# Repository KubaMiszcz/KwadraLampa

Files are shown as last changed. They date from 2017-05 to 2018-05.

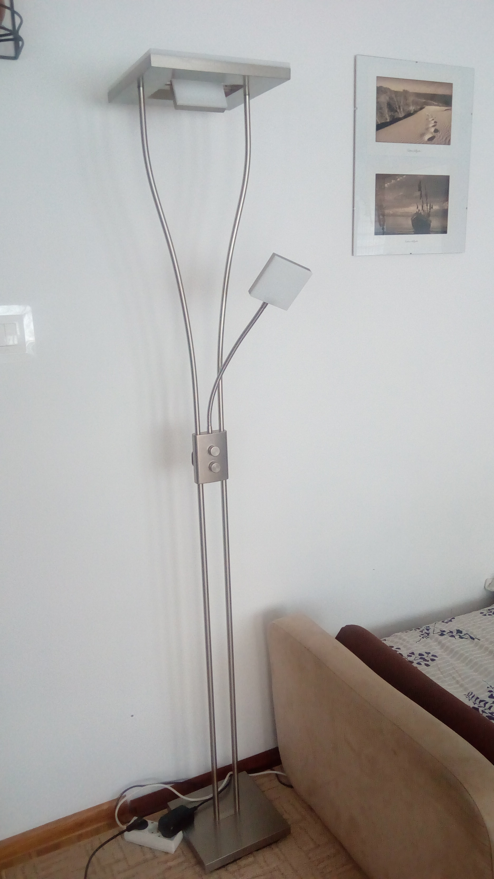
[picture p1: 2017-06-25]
foto/2017-06-14 105750.jpg

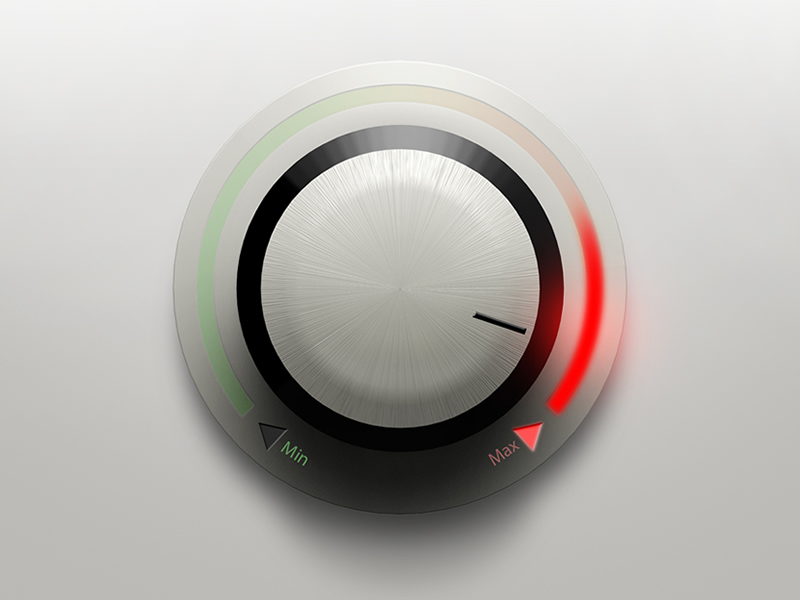
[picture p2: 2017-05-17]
grafiki/rotary knob/ui-button-smooth-red-800x600.jpg

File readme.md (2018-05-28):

# KwadraLampa
## TODO:
* rewrite to STM32F103
* communication through wifi - mosquitto and openhab
* redesign PCB for it

## Android App
* ikonka help i about
* ikonka powrot do glownego
* pamietanie ostatniego nadajnika i laczenie automatyczne
* krotkie nazwy nadajnikow
* usun dzwieki na razie bo cos sie krzwayc i za dlugo trwaja nawt po wylaczneiu

## PC Client
* todo

## Arduino firmware
sprawdz czy arduino wysyla co 100ms 10ms przy 9600, jak tak to kombinu z xamarinem:]
ustwiaenia BT i inne do ekranu ustwaienia
komunikacja w obie strony

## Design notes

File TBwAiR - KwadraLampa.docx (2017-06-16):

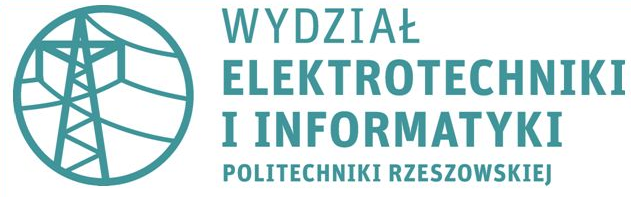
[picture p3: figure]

Dokumentacja do projektu z przedmiotu:

Technologie Bezprzewodowe w Automatyce i Robotyce

Sterownik BlueTooth

do Lampy LED

KwadraLampa

LP1 C1, EADI-3

Bełch Jakub

Rzeszów, IV 2017

1. Cel i zakres projektu

Projekt miał na celu wykonanie sterownika do pokojowej stojącej Lampy LED, można go również użyc do innych zastosowań. Zakres obejmował wykonanie firmwaru do mikrokontorolera oraz klienta na Android i PC. Z braku czasu na tę chwilę zrezygnowałem z wykonania klienta na PC.

Podstawowe założenia:

- właczanie/wyłaczanie lamp
- regulacja jasności
- właczanie/wylaczanie po zadanym czasie – TIMER
- właczanie/wyłaczanie o zadanej godzinie – CLOCK

Dodatkowo w trybach CLOCK i TIMER mozna ustawic opcje ze zamiast naglego wylaczenia po zadanym czasie lampa sciemnia/rozjasnia sie stopniowo do 0/255 w ciagu tego czasu.

Na razie w trybach timer i clock działa tylko wyłączanie, muszę pomyśleć jak zrealizować to rozróżnienie

Komunikacja bezprzewodowa realizowana jest przez dowolny modul BT w trybie SPP

2. Ogólny opis rozwiązania

Zadanie było w miarę proste jednak wymagało troche czasu zeby wszystko dzialalo wygodnie. sterowanie realizowane jest w dwoch trybach MANUAL i BLUTUTU. Obsluga obu lamp jest identyczna.

tryb Manual:

Wykorzystalem dostepny fizyczny interfejs tzn dwie galki, z braku potencjometrow z wylacznikiem, wylaczanie polega na skreceniu potencjometrow na 0, regulacja polega na kreceniu galkami. Lampa ma byc prosta intuicyjna w oblsudze i wygodna dla postronnych osob dlatego nie mnozylem dalszych kontrolek

tryb Blututu:

Realizowany jest na zasadzie przesylanie kilkunastu komunikatow sterujacych plytka. Dostepne opcje:

- gaszenie/zapalanie przyciskiem
- regulacja jasnosci
- właczanie/wylaczanie po zadanym czasie – timer
- właczanie/wyłaczanie o zadanej godzinie – clock

Dodatkowo w trybach clock i timer mozna ustawic opcje ze zamiast naglego wylaczenia po zadanym czasie lampa sciemnia sie stopniowo do 0 w ciagu tego czasu (nieliniowo poniewaz jasnosc diody nie maleje liniowo wraz z pradem).

Przed podlaczeniem konieczne jest sparowanie urzadzenia z telefonem

Aaby moc korzystac z trybu clock konieczna jest znajomosc rzeczywistego czasu, poniewaz nie jest to jakos szczegolnie wazne zrezygnowalem z jakiegos modulu podtrzymywania/pobierania go, a rozwiazalem to w ten sposob ze po polaczeniz Klientem na ktorym mamy aktualny czas jest on przesylany i uaktualniany w sterowniku,

Czas w sterowniku przekreca sie co ok 40 dni, i kasuje po zaniku zasilana, jednak przy sterowaniu recznym i tak jest zbedny a po polaczeniu z BT jest ustawiany wiec ten problem uznalem za rozwiazany

Komunikaty sterujace:

3. Komunikaty do sterownika

Długosc komunikatu 11znakow (wazne! aczkolwiek firmware dopelnia sam do 11 znakow jesli dostał krotszy komunikat, jesli dostal dluzszy, sprawdza ostatnie 11znakow)

Liczby lepiej byłoby przesylac jako bajty (krocej) ale potem trza by konwertowac na stringi, na etapie prototypowania prosciej wysylac jako stringi/char.

Tak samo tryby i w ogole komunikaty, docelowo lepiej przerobic na typ ENUM i wtedy wysylamy jako jeden bajt caly string – ale trzeba by wtedy pamietac w terminalu te "kody" trybow

Spis komunikatów:

Zapytania do sterownika:
::HM:? | Przeslanie aktualnego czasu ze sterownika do klienta
::L1:? | Odsyla stan lampy do klienta
::L1:DIM? | Odsyla stan opcji sciemniania do klienta
::L1:BRGHT? | Odsyla aktualna jasnosc lampy

Ustawienia sterownika:
::HM:hhmm | Przeslanie aktualnego czasu do sterownika
::L1:on ::L1:off | Wyl/zal lampy 1
::L1:PWM5 ::L1:PWM55 ::L1:PWM255 | Przeslanie zadanej jasnosci
::L1:DIMon ::L1:DIMoff | Wyl/zal sciemnianie opcji sciemniania dla trybu timer i clock
::L1:CLhhmm ::L1:CLhhmm | Wyl/zal lampy o zadanej godzinie
::L1:TIM5 ::L1:TIM55 ::L1:TIM255 | Wyl/zal lampy po zadanym czasie
::L1:TIcncl | Anulowanie timera
::L1:CLcncl | Anulowanie clock
::L1:TGLon | Po zadanym czasie/godzine lampa sie wlacza
::L1:TGLoff | Po zadanym czasie/godzine lampa sie wylacza

Analogicznie dla lampy L2 ,Szczegolowy opis firmware – dalej

4. Sprzęt

Lampa

Lampa sklada sie z dwoch modułów LED 20W + 4W, sterowanie kazda lampa osobno, wylaczenie lampy realizowane jest przez skrecenie jasnosci do 0, lub ustawienie jej programowo na 0 (zatkanie tranzystora MOSFET)

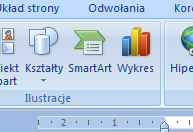
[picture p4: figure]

ZDJECIE

Płytka PCB

W zwiazku z zasilaniem 20V i maksymalnym prądem ok 1A konieczne bylo zastosowanie tranzystora sterowanego PWM (0-255 ok. 1kHz) jako regulatora, wybor padl na MOSFET IRFZ44N gdyz jest w miare uniwerslany, miałem go pod ręka, dla takich parametrów prawie sie nie grzeje (nie trzeba radiatora), i pobiera duzo mniej mocy niz analogiczny bipolarny.

Logikę zrealizowałem za pomocą mikrokontrolera Atmega8A z bootloaderem Arduino

zdjecie i schemat

Klienty

- Android – telefon z androidem, apka w AppInventor
- PC – dowolny terminal RS, lub program np w C# + kontrolka SerialPort

Firmware

Platforma Arduino, C++, programowanie obiektowe

5. Opis firmware

wiekszosc jest wyjasniona w komentarzach w kodzie

Ogolnie firmware posiada klase Lampa, i dwa obiekty tej klasy, zestaw metod do nich, plus pomocnicze statyczne metody w SharedObjectsClass, enumerator trybow, operacje na czasie itp.

podczas dzialania sprawdza stan na pinach. po wykryciu prawidlowego komunikatu przechodzi w tryb BT, nie obowiazuja wtedy ustawienia galek, po wykryciu zmiany na galkach przestaja obowiazywac ustawienia BT (zerowane sa timery)

oblsuga trybu CLOCK jest zrealizowana za pomoca trybu timer – jest wyliczany czas miedzy zadana godizna i aktualna i wykonywana metoda dla TIMER

6. Podsumowanie i Wnioski

brak pamieci

stm32

app inventor

7. Planowane Upgrady

Klient Android

- dzwieki on/off
- krotkei nazwy nadajnikow na liscie
- domsylny nadajnik zapisz , zapis aktulany jako odmyslny
- lacz przy starcie z domyslny,
8. do zrobienia
9. ogolnie
- wylaczanie o zadanej godzinie
- rozjasnianie
10. ==========APKA ANDROID
- ikonka help i about
- ikonka powrot do glownego
- pamietanie ostatniego nadajnika i laczenie automatyczne
- krotkie nazwy nadajnikow
- usun dzwieki na razie bo cos sie krzwayc i za dlugo trwaja nawt po wylaczneiu
11. ==========PROGRAM PC
12. ==========FIRMWARE ARDUINO
13. ==========inne
- zaloz konto GOOGLE PLAY
- jak przyspieszyc ten BT
- sprawdz czy arduino wysyla co 100ms 10ms przy 9600, jak tak to kombinu z xamarinem:]
- ustwiaenia BT i inne do ekranu ustwaienia
- komunikacja w obie strony
- hithub repo
15. Rozwiązania konstrukcyjne

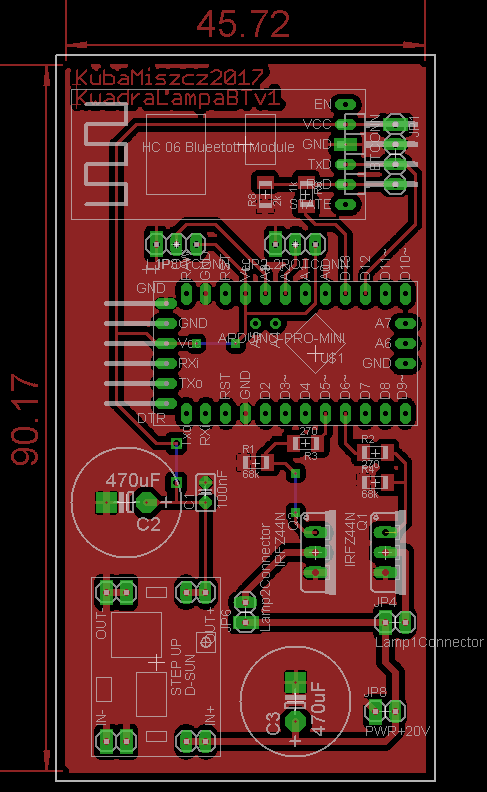
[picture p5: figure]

Konstruk).

17. Algorytm

XXXXXXX

18. Napotkane Problemy

wysylaniue co 1sek

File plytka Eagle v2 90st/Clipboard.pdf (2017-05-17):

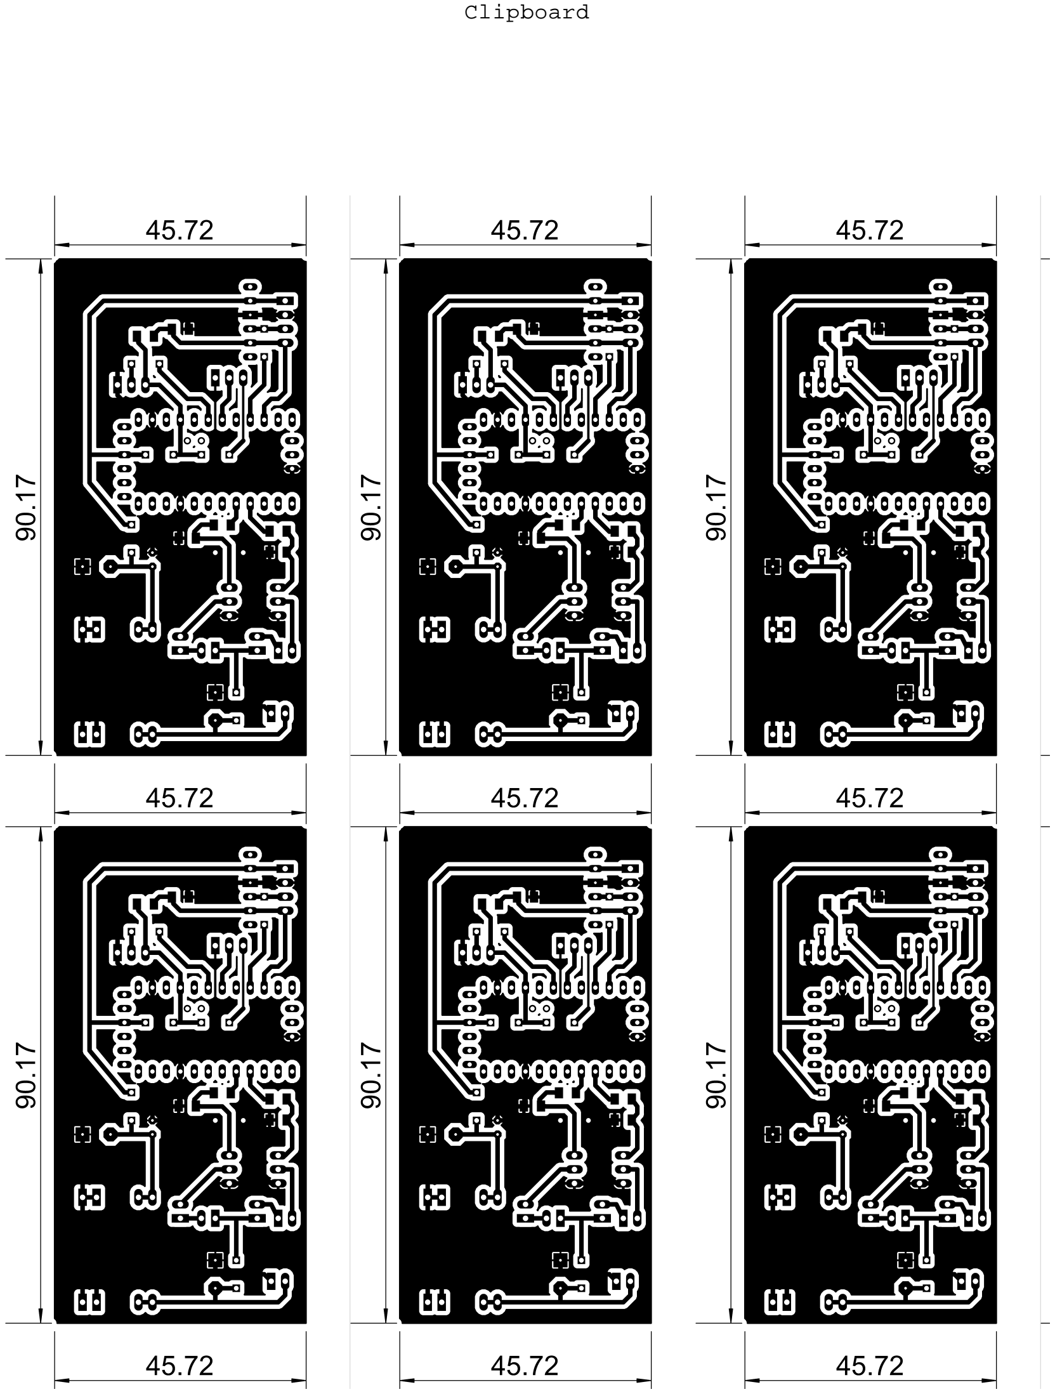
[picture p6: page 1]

Clipboard

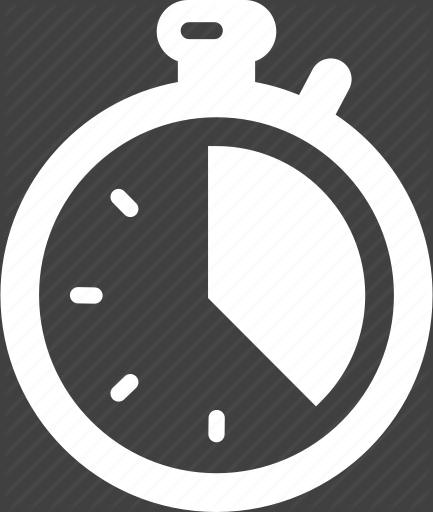
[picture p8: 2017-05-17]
grafiki/=accepted/Timer-512inv.png

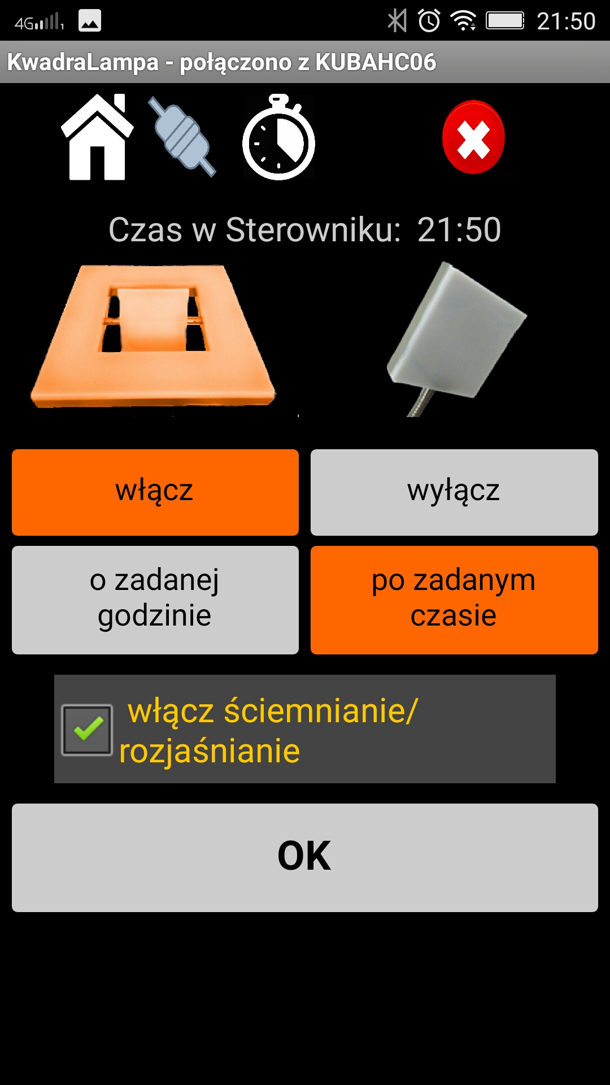
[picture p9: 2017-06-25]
foto/Screenshot_20170625-215026-410.jpg

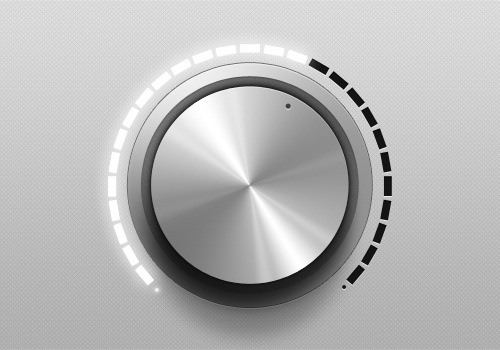
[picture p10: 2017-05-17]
grafiki/rotary knob/4-33-beautiful-volume-dials.jpg

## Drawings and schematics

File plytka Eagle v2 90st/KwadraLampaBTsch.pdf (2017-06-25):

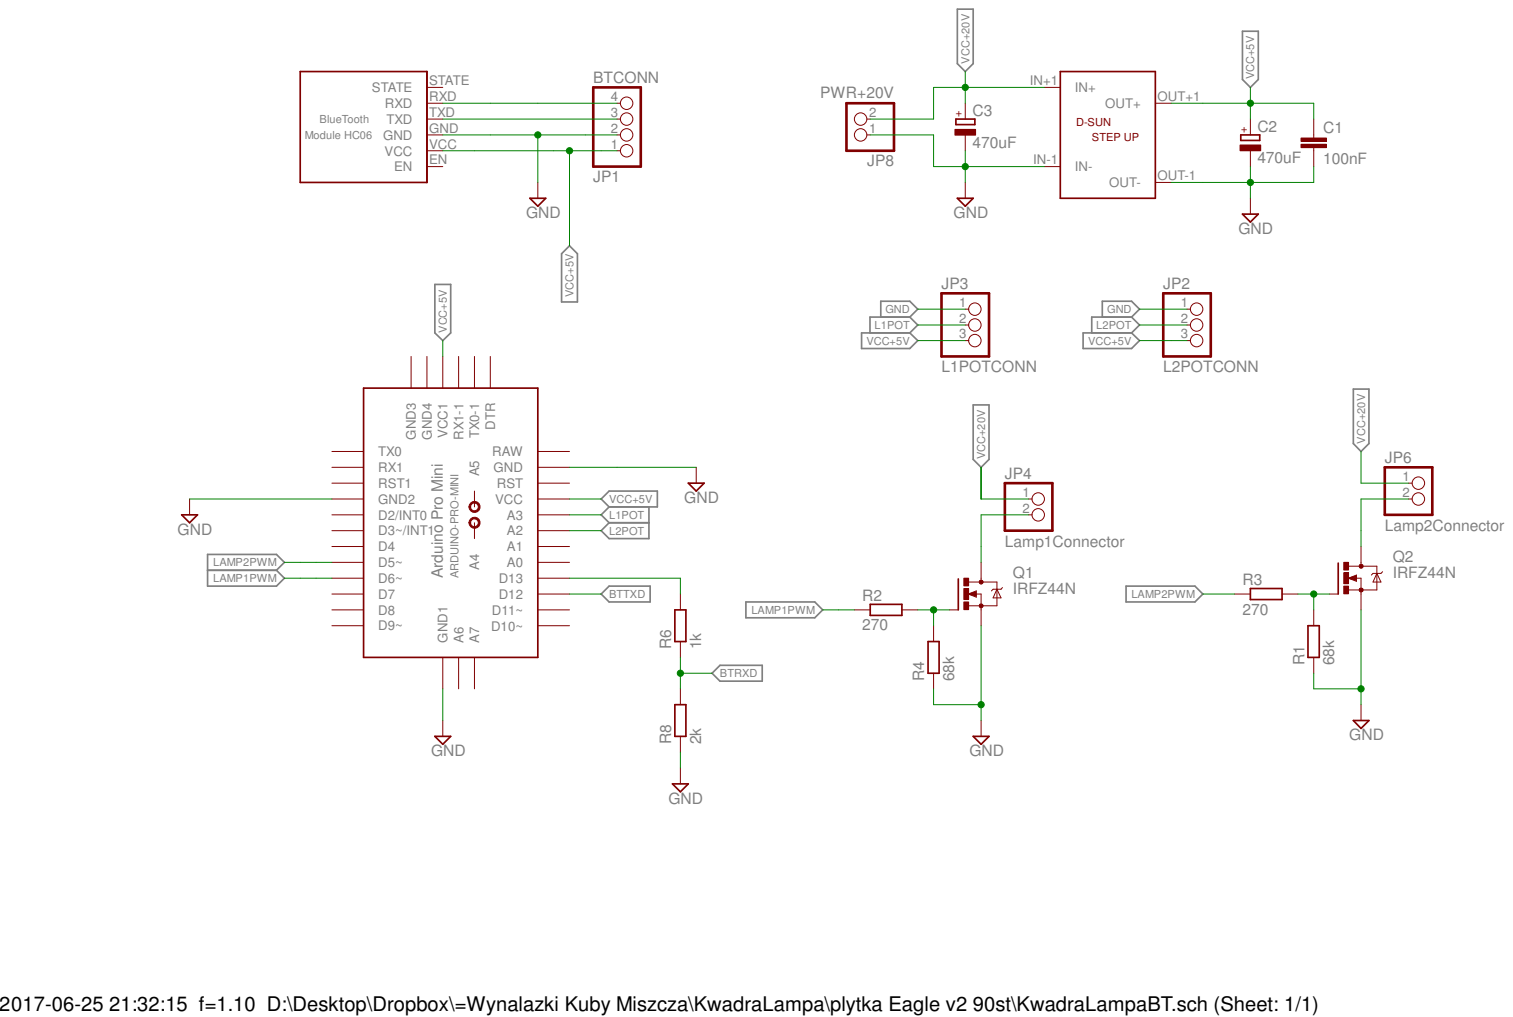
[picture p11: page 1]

ARDUINO-PRO-MINI GND

2017-06-25 21:32:15 f=1.10 D:\Desktop\Dropbox\=Wynalazki Kuby Miszcza\KwadraLampa\plytka Eagle v2 90st\KwadraLampaBT.sch (Sheet: 1/1)

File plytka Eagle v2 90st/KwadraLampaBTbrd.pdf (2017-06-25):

45.72

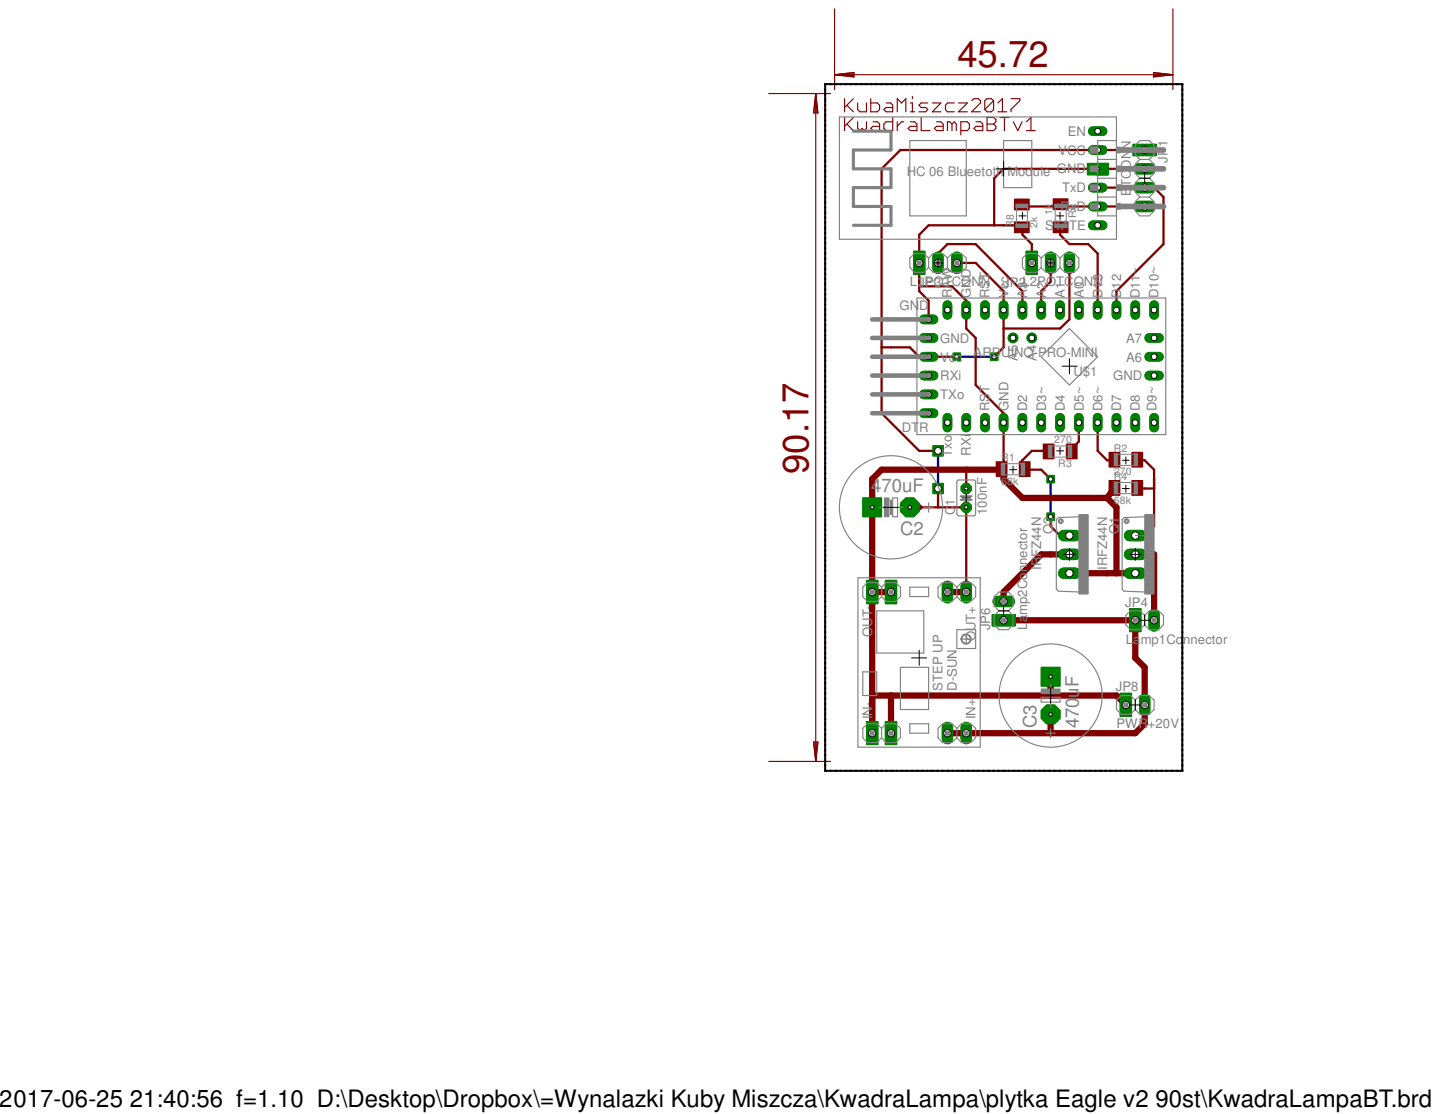
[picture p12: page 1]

L2POTCONN

TXo

2017-06-25 21:40:56 f=1.10 D:\Desktop\Dropbox\=Wynalazki Kuby Miszcza\KwadraLampa\plytka Eagle v2 90st\KwadraLampaBT.brd

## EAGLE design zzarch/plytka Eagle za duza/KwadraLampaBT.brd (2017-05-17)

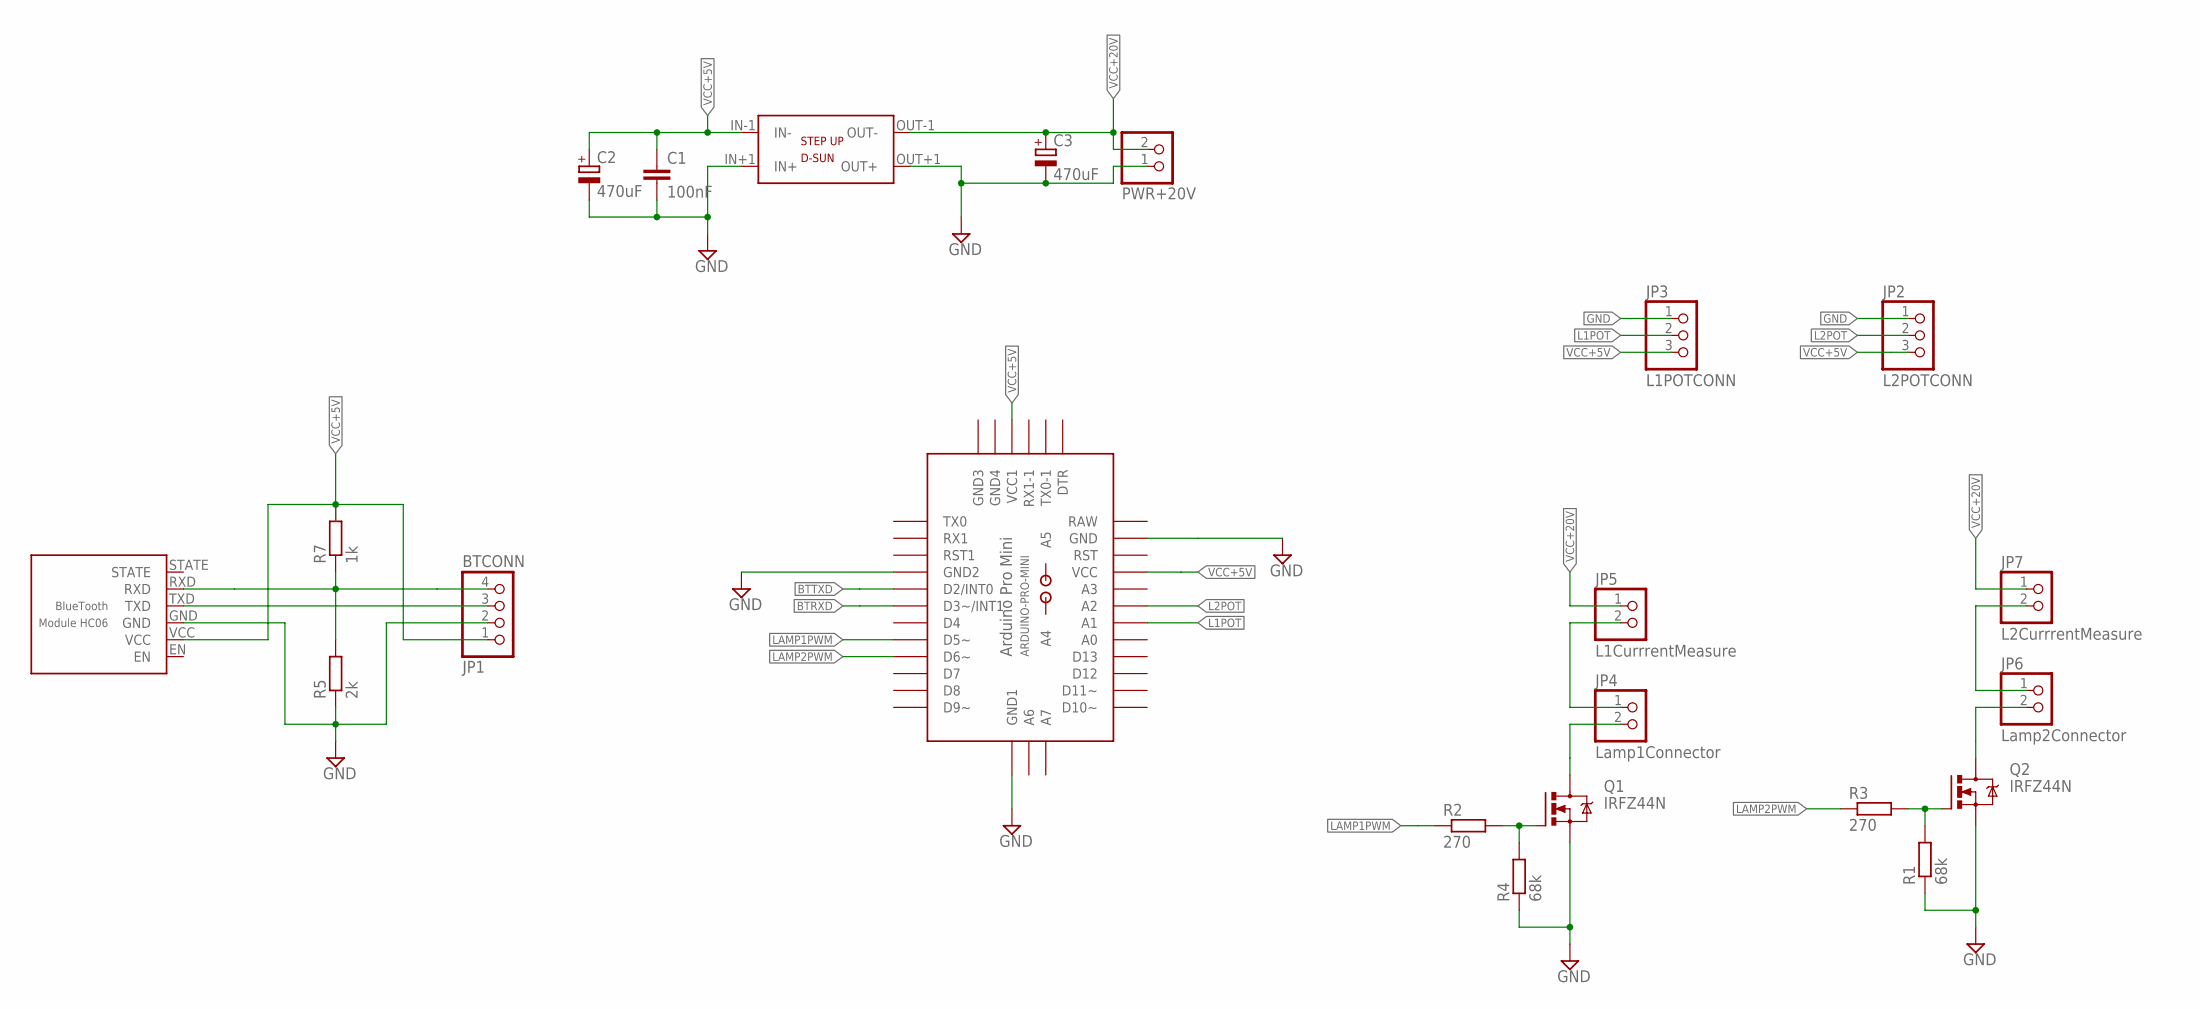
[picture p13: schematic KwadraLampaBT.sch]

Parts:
C1: 100nF; C025-025X050
C2, C3: 470uF; C_E_R5-FI13_ELECTROLYTIC
IC1: HC06
JP1: BTCONN; 1X04
JP2: L2POTCONN; 1X03
JP3: L1POTCONN; 1X03
JP4: Lamp1Connector; 1X02
JP5: L1CurrrentMeasure; 1X02
JP6: Lamp2Connector; 1X02
JP7: L2CurrrentMeasure; 1X02
PWR+20V: PINHD-1X2; 1X02
Q1, Q2: IRFZ44N; TO220AB-GDS-VERT
R1, R4: 68k; SMD1206
R2, R3: 270; SMD1206
R5: 2k; SMD1206
R7: 1k; SMD1206
U$1: ARDUINO-PRO-MINI
U$2: STEPUP_D-SUN

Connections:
BTRXD: IC1.RXD, JP1.4, R5.2, R7.1, U$1.D3 (D3~/INT1)
BTTXD: IC1.TXD, JP1.3, U$1.D2 (D2/INT0)
GND: C1.2, C2.-, C3.-, IC1.GND, JP1.2, JP2.1, JP3.1, PWR+20V.1, Q1.S, Q2.S, R1.1, R4.1, R5.1, U$1.GND, U$1.GND1 (GND2), U$1.GND4 (GND1), U$2.IN+1 (IN+), U$2.OUT+1 (OUT+)
L1POT: JP3.2, U$1.A1
L2POT: JP2.2, U$1.A2
LAMP1PWM: R2.1, U$1.D5 (D5~)
LAMP2PWM: R3.1, U$1.D6 (D6~)
unnamed: JP4.2, Q1.D
unnamed: JP6.2, Q2.D
unnamed: Q2.G, R1.2, R3.2
unnamed: Q1.G, R2.2, R4.2
unnamed: JP4.1, JP5.2
unnamed: JP6.1, JP7.2
VCC+5V: C1.1, C2.+, IC1.VCC, JP1.1, JP2.3, JP3.3, R7.2, U$1.VCC, U$1.VCC1, U$2.IN-1 (IN-)
VCC+20V: C3.+, JP5.1, JP7.1, PWR+20V.2, U$2.OUT-1 (OUT-)

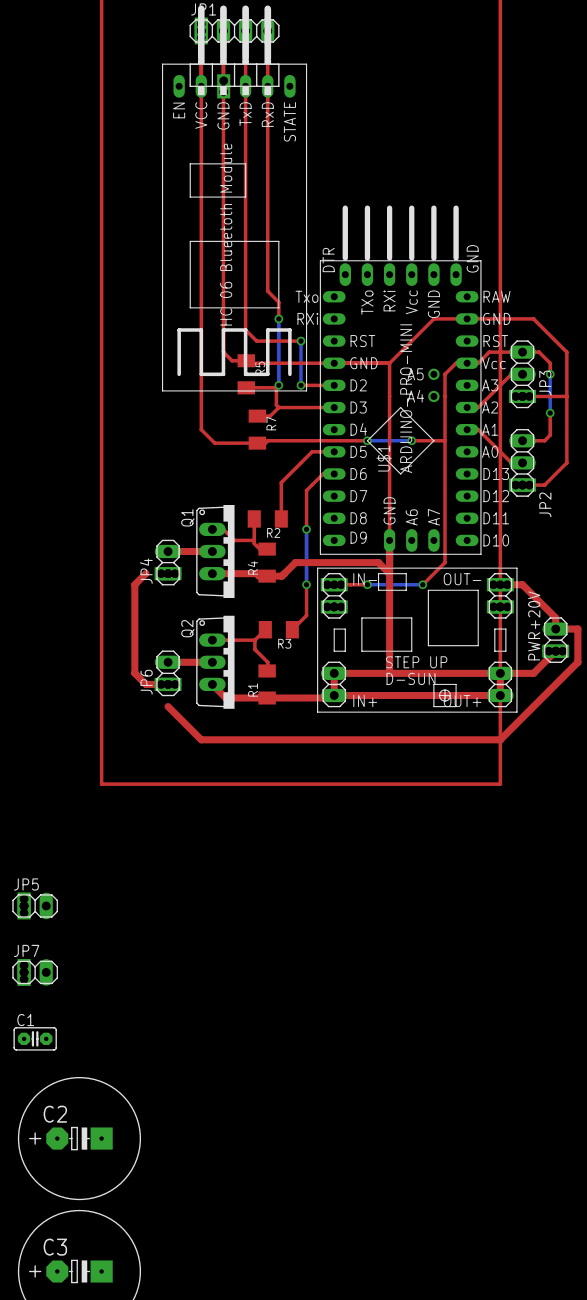
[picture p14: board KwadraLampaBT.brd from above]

Board: 2 copper layers, 22 parts (0 on the bottom side), 15 nets.

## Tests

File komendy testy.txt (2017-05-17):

::L1:onxxxx
::L1:offxxx
::L1:PWM200
::L1:PWMx20
::L1:TIMxx5
::L1:TIMx20

::L2:onxxxx
::L2:offxxx
::L2:PWM200
::L2:PWMx20
::L1:TIMxx5
::L1:TIMx20

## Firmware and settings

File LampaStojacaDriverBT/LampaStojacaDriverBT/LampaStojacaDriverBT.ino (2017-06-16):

/*
  Blink
  Turns on an LED on for one second, then off for one second, repeatedly.

  Most Arduinos have an on-board LED you can control. On the Uno and
  Leonardo, it is attached to digital pin 13. If you're unsure what
  pin the on-board LED is connected to on your Arduino model, check
  the documentation at http://arduino.cc

  This example code is in the public domain.

  modified 8 May 2014
  by Scott Fitzgerald
 */

 /*
 jak dzial starts with cyz licz od 0
 i czy aa.startswith("aa") jest ok?
 */


 // the setup function runs once when you press reset or power the board
#include <SoftwareSerial.h>
#include "Lamp.h"
#include "SharedObjects.h"
//#include <EEPROM.h>

//stale
const uint8_t numLamps = 2;
enum Modes { Manual = 0, Blututu };
const unsigned long int OneSecondInMillis = 1000;
const unsigned int CycleDelay = 10;

//komunikaty IN
//const String MsgSetClock = "HM:";
//const String MsgGetClock = "HM:?";

//komunikaty OUT


//pinout
//Lampa 1 - gorna 20W
const uint8_t inLamp1BrightnessPot = A2;
const uint8_t outLamp1OutPWM = 6;
LampClass Lamp1("L1", inLamp1BrightnessPot, outLamp1OutPWM);

//!!!!!!!!!! 
//nazwy musza byc L1 L2... bo tak jest potem w komunikatach na sztywno ustawione inna nazwa i komunikat nie zadziala
//!!!!!!!!!!!!!!

//Lampa 2 - gorna 4W
const uint8_t inLamp2BrightnessPot = A1;
const uint8_t outLamp2OutPWM = 5;
LampClass Lamp2("L2", inLamp2BrightnessPot, outLamp2OutPWM);

//software serial
SoftwareSerial mySerial(13, 12); // RX, TX

LampClass Lamps[] = { Lamp1,Lamp2 }; //3 zeby nie zaczynac od indeksu 1-L1, 2-L2


//zmienne
String incomingMesg = "";
int readings[] = { 0,0,0 };
unsigned long int NextTick;
//unsigned int Hours = 0, Minutes = 0, Seconds = 0;
Time currentTime;
//SharedObjectsClass SharedObjects;

void setup() {
	Serial.begin(9600);
	Serial.println("hello serial");
	mySerial.begin(9600);
	mySerial.println("hello Myserial v2");
	pinMode(inLamp1BrightnessPot, INPUT);
	pinMode(outLamp1OutPWM, OUTPUT);
	pinMode(inLamp2BrightnessPot, INPUT);
	pinMode(outLamp2OutPWM, OUTPUT);
	NextTick = millis() + OneSecondInMillis;//+1 second

	for (int i = 0; i < numLamps; i++)
	{
		UpdateReadings(i, Lamps[i].inBrightnessPot);
		Serial.print("i= " + String(i));
		Serial.print(" name= " + Lamps[i].Name);
		Serial.print(" pin= " + String(Lamps[i].inBrightnessPot));
		Serial.println(" read= " + String(readings[i]));
		Lamps[i].SetBrightness(readings[i]);
		Lamps[i].IsTurnedON = false;
		Lamps[i].prevBTBrightness = Lamps[i].currentBrightness;
		Lamps[i].prevManualBrightness = Lamps[i].currentBrightness;
	}
}

//void loop2() {
//	int read = analogRead(Lamp1.inBrightnessPot);//0-1023
//	Serial.print(read); Serial.print(" ");
//	int curManBrightness = map(read, 0, 1023, 0, 255);//0-255
//	Serial.print(curManBrightness); Serial.print(" ");
//	Lamp1.SetBrightness(curManBrightness);
//	Serial.print(Lamp1.currentBrightness); Serial.print(" \n");
//}


// the loop function runs over and over again forever
void loop() {
	delay(CycleDelay);
	//########## dodaj pobieranie satusu zmiennych zeby poustwaiac kontrolki w apce przy polaczeniu 
	//przeyslanie timera stanow alampek jasnosci itp
	String str = ReceiveMesg();	//odebranie wiadomosci z nadajnika 
	SendMesg();
	UpdateClock();
	//ReceiveMesg222();
	//UpdateClockv2(&Seconds);

	for (uint8_t i = 0; i < numLamps; i++)
	{
		//##############################################
		//zzaczynamy w trybie manual
		//##############################################
#pragma region MANUAL currentMode
		if (Lamps[i].currentMode == Modes(Manual))	//MANUAL
		{	//przejsice w blututu
			if (str.startsWith(Lamps[i].Name))
			{
				Lamps[i].currentMode = Modes(Blututu);
				Lamps[i].prevMode = Modes(Manual);

				Serial.println("curmode " + Lamps[i].Name + " =man>>BT"
					+ String(Lamps[i].currentMode) + " "
					+ String(Lamps[i].currentBrightness));

				//zapamietanie ostatneigo brighness w MAN
				UpdateReadings(i, Lamps[i].inBrightnessPot);
				Lamps[i].prevManualBrightness = readings[i];
			}
			else {	//zostajemy w manual
				UpdateReadings(i, Lamps[i].inBrightnessPot);
				//Serial.print("man analog read " + String(read));
				//Serial.println(" man mapped analog readings[i] " + String(readings[i]));
				Lamps[i].SetBrightness(readings[i]);
				//if (Lamps[i].currentBrightness < 5)
				//{
				//	//mySerial.println("::L1:PWM" + String(Lamp1.currentBrightness) + "\n");
				//}
			}
		}
#pragma endregion

		//##############################################
		//a teraz jesli tryb BT	//blutut
		//##############################################
#pragma region Blutut Mode
		if (Lamps[i].currentMode == Modes(Blututu))	//BLUTUT
		{
			Lamps[i].ActionOnTimer(); //tylko w btmode, w manual nie ma timera
			//czy przejsc w man mode
			UpdateReadings(i, Lamps[i].inBrightnessPot);
			if (
				(readings[i] > (Lamps[i].prevManualBrightness + 10))		//filtre bo ADC plywa moze dodoac jakies 100nF?
				||
				(readings[i] < (Lamps[i].prevManualBrightness - 10)))
			{
				Lamps[i].currentMode = Modes(Manual);
				Lamps[i].prevMode = Modes(Blututu);
				Lamps[i].SetBrightness(readings[i]);
				Serial.println("curmode= " + Lamps[i].Name + " BT>>MAN"
					+ String(Lamps[i].currentMode) + " "
					+ String(Lamps[i].currentBrightness));
			}
			else if (str.startsWith(Lamps[i].Name)) {
				Serial.println(str);
				Lamps[i].ActionOnMessage(str);//a co z tym stringiem zrobic robi metoda w klasie
			}
		}
#pragma endregion 
	}
	//##########KONIEC PRZELATYWANIA PO TABLICY LAMP


	//#############ZAPYTANIA DO STEROWNIKA
	//Przy przesylania pamietaj zeby dlugosc komunikatu byla 11 znakow
	//dodaj te :: na poczatku, ale juz do rozpoznawanie jest bez tych ::
	//###### ZAPYTANIA LUB USTAWIANIE PARAMETROW STEROWNIKA
	if (str.startsWith("HM:")) {		//HM:1234xx
		if (str.startsWith("HM:?")) {		//ktora godizna
			mySerial.println("Clock: " + String(currentTime.H) + ":" + String(currentTime.M) + ":" + String(currentTime.S));
			Serial.println("Clock send: " + String(currentTime.H) + ":" + String(currentTime.M) + ":" + String(currentTime.S));
		}
		else	//ustawianie zegara
		{
			currentTime.H = str.substring(3, 5).toInt();
			currentTime.M = str.substring(5, 7).toInt();//
			SharedObjects.SetTime(currentTime.H, currentTime.M, currentTime.S);
			Serial.println("Clock Updated: " + String(currentTime.H) + ":" + String(currentTime.M) + ":" + String(currentTime.S));
		}
	}

}

String ReceiveMesg() {
	String str = "";
	if (mySerial.available() > 0) {
		str = mySerial.readString();
		str.trim();
		Serial.println("Received>> " + str);	//echo na sterownik
		if (str.startsWith("::")) {
			if (str.length()>11) {
				str = str.substring(str.length() - 9); //9 osttanich znakow, juz bez "::"
			}
			else {
				str =str+"xxxxxxxxxxx";		//dopelnienie do 11 znakow
				str = str.substring(2, 11);
			}
		}
		else str = "";
	}
	else str = "";
	return str;
}

void SendMesg() {
	if (SharedObjects.MessageToSend != "") {
		mySerial.println(SharedObjects.MessageToSend);
		SharedObjects.MessageToSend = "";
	}
}

//void ReceiveMesg222() {
//	String str = "";
//	if (Serial.available() > 0) {
//		str = Serial.readString();
//		Serial.println("Received222>> " + str);
//	}
//}


void UpdateReadings(uint8_t i, uint8_t BrightnessPotentiometer) {
	readings[i] = analogRead(BrightnessPotentiometer);//0-1023
	readings[i] = map(readings[i], 0, 1023, 0, 255);//0-255
}

void UpdateClock() {
	if (millis() > NextTick)
	{
		currentTime.S += 1;
		if (currentTime.S >= 60)
		{
			currentTime.S = 0;
			currentTime.M += 1;
			Serial.println("CLK: " + String(currentTime.H) + ":" + String(currentTime.M) + ":" + String(currentTime.S));
			if (currentTime.M >= 60)
			{
				currentTime.M = 0;
				currentTime.H += 1;
				if (currentTime.H >= 24) {
					currentTime.H = 0;
				}
			}
		}
		SharedObjects.SetTime(currentTime.H, currentTime.M, currentTime.S);
		//Serial.println("CLK: " + String(currentTime.H) + ":" + String(currentTime.M) + ":" + String(currentTime.S));
		NextTick += OneSecondInMillis;
	}
}

//void UpdateClockv2(unsigned int* ss) {
//	if (millis() > NextTick)
//	{
//		*ss = *ss + 1;
//
//		if (*ss >= 60)
//		{
//			*ss = 0;
//		}
//		String str = String(*ss);
//		Serial.println("CLK: " + str);
//		NextTick += SecondInMillis;
//	}
//}

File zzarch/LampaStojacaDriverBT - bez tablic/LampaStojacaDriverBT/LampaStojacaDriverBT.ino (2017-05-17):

/*
  Blink
  Turns on an LED on for one second, then off for one second, repeatedly.

  Most Arduinos have an on-board LED you can control. On the Uno and
  Leonardo, it is attached to digital pin 13. If you're unsure what
  pin the on-board LED is connected to on your Arduino model, check
  the documentation at http://arduino.cc

  This example code is in the public domain.

  modified 8 May 2014
  by Scott Fitzgerald
 */

/*
jak dzial starts with cyz licz od 0
i czy aa.startswith("aa") jest ok?
*/


// the setup function runs once when you press reset or power the board
#include <SoftwareSerial.h>
#include "Lamp.h"
//pinout
int inLamp1BrightnessPot=A1;
int outLamp1OutPWM = 5;
int inLamp2BrightnessPot = A2;
int outLamp2OutPWM = 6;
SoftwareSerial mySerial(13, 12); // RX, TX

//zmiene
String incomingMesg="";
enum modes { Manual = 0, Blututu };

//klasy
LampClass Lamp1(inLamp1BrightnessPot, outLamp1OutPWM);
LampClass Lamp2(inLamp2BrightnessPot, outLamp2OutPWM);

void setup() {
	Serial.begin(9600);
	Serial.println("hello serial");
	mySerial.begin(9600);
	Serial.println("hello Myserial");
    pinMode(inLamp1BrightnessPot, INPUT);
	pinMode(outLamp1OutPWM, OUTPUT);
	pinMode(inLamp2BrightnessPot, INPUT);
	pinMode(outLamp2OutPWM, OUTPUT);
	
	int read;
	read = analogRead(Lamp1.inBrightnessPot);//0-1023
	Serial.println(read);
	Lamp1.currentBrightness = map(read, 0, 1023, 0, 255);//0-255
	Lamp1.SetBrightness(Lamp1.currentBrightness);
	Lamp1.IsTurnedON = false;

}

void loop2() {
	int read = analogRead(Lamp1.inBrightnessPot);//0-1023
	Serial.print(read); Serial.print(" ");
	int curManBrightness = map(read, 0, 1023, 0, 255);//0-255
	Serial.print(curManBrightness); Serial.print(" ");
	Lamp1.SetBrightness(curManBrightness);
	Serial.print(Lamp1.currentBrightness); Serial.print(" \n");
}


// the loop function runs over and over again forever
void loop() {
	delay(50);
	
	//##############################################
	//wartosci current
	//##############################################
	String str = ReceiveMesg();
	int read;

	//##############################################
	//zzaczynamy w trybie manual
	//##############################################
#pragma region MANUAL mode
	if (Lamp1.mode==modes(Manual))	//MANUAL
	{
		if (str.startsWith("L1"))
		{
			Lamp1.mode = modes(Blututu);
			Lamp1.prevMode = modes(Manual);

			Serial.println("curmode=man>>BT" + String(Lamp1.mode)+" " + String(Lamp1.currentBrightness));
			mySerial.println("curmode=man>>BT" + String(Lamp1.mode) + " " + String(Lamp1.currentBrightness));
			
			//zapamietanie ostatneigo brighness w MAN
			read = analogRead(Lamp1.inBrightnessPot);
			read = map(read, 0, 1023, 0, 255);
			Lamp1.prevManBrightness=read;
		}
		else {
				read = analogRead(Lamp1.inBrightnessPot);
				//Serial.print("man analog read " + String(read));
				read = map(read, 0, 1023, 0, 255);
				//Serial.println(" man mapped analog read " + String(read));
				Lamp1.SetBrightness(read);
				if (Lamp1.currentBrightness<5)
				{
					//mySerial.println("::L1:PWM" + String(Lamp1.currentBrightness) + "\n");
				}

		}
	}
#pragma endregion

	//##############################################
	//a teraz jesli tryb BT	//blutut
	//##############################################
#pragma region Blutut Mode
	if (Lamp1.mode == modes(Blututu))	//BLUTUT
	{
		//czy przejsc w man mode
		int read = analogRead(Lamp1.inBrightnessPot);
		read = map(read, 0, 1023, 0, 255);
		if ( 
			(read > (Lamp1.prevManBrightness+5))
			|| 
			(read < (Lamp1.prevManBrightness-5)) )
		{
			Lamp1.mode = modes(Manual);
			Lamp1.prevMode = modes(Blututu);
			Lamp1.SetBrightness(read);
			Serial.println("curmode=BT>>MAN" + String(Lamp1.mode)+ " "+String(Lamp1.currentBrightness));
			mySerial.println("curmode=BT>>MAN" + String(Lamp1.mode) + " " + String(Lamp1.currentBrightness));
		}
		else
		{
			if (str.startsWith("L1")) {
				Lamp1.SendMesg(str);//a co z tym stringiem zrobic robi metoda w klasie
			}
		}
	}

#pragma endregion

	//##############################################
	//wart prev
	//##############################################
}

String ReceiveMesg() {
	String str = ""; 
	if (mySerial.available() > 0) {
		str = mySerial.readString();
		mySerial.println("echo>>"+str);
		if (str.startsWith("::")) {
			str = str.substring(str.length()-9); //9 osttanich znakow
			Serial.println(str);
			mySerial.println("echo>>" + str);
		}
		else str = "";
	}
	else str = "";
	return str;
}
